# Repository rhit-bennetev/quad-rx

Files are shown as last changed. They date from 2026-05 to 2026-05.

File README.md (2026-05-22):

# quad-rx
Repository for the QuadRX gaming controller, created by Rose-Hulman 2026 ECE Capstone Team 11.

# FIRMWARE SETUP
A guide on how to use the controller from the perspective of the user is included in the final report. This guide is for power users, or manufacturers. 
We do not have access to the steps used to create the controller housing, nor integrate the basic parts such as the joystick, keycap buttons, or other ports. 
Since all of this was done by QuadRX, this guide will focus on our contribution to the project.

To compile and flash our firmware, version 2.3.7 of the Arduino IDE is required. In the future, new versions may work, but at the time of writing 
versions 2.3.8 and newer do not compile. 

Once the IDE is installed, next install the LittleFS Filesystem Uploader. This tutorial is the one we followed, and explains the process well.
https://randomnerdtutorials.com/arduino-ide-2-install-esp32-littlefs/

Next, make sure you have the newest version of git installed
https://github.com/git-guides/install-git

Clone the repository somewhere on your machine.

From here, open ControllerFirmware.ino.

Follow the steps in the LittleFS tutorial previously linked to upload the files necessary to your TinyPico. 

Then, press the arrow button in the top left corner of the IDE to compile and flash the firmware to the board. 

# HARDWARE SETUP

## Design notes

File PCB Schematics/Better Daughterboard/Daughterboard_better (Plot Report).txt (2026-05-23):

Plot Report
-----------

Report Written:     19:05 Friday, May 22, 2026
Design Path:        C:\Users\metcalwh\OneDrive - Rose-Hulman Institute of Technology\Documents\ECE362\Projects\Daughterboard_better.pcb
Design Title:       
Created:            1/16/2026 3:17:17 PM
Last Saved:         5/22/2026 7:00:21 PM
Editing Time:       15541 min
Units:              mm (precision 2)

Device Settings
===============

Gerber Settings
===============

    Leading zero suppression.
    G01 assumed throughout.
    Line termination <*> <CR> <LF>.
    3.5 format absolute inches.

    Format commands defined in Gerber file.
    Aperture table defined in Gerber file.
    Hardware arcs allowed.

Drill Settings
==============

    Excellon Format 2
    Format 3.5 absolute in mm.
    Zero suppression Leading

Plots Output
============

    Plot Job: "C:\Users\metcalwh\OneDrive - Rose-Hulman Institute of Technology\Documents\ECE362\Projects\Daughterboard_better.mop"

Gerber Output
=============

C:\Users\metcalwh\OneDrive - Rose-Hulman Institute of Technology\Documents\ECE362\Projects\Daughterboard_better - Top Gerber.gbr

    Layers:
    --------------
    Top Copper

    D-Code Shape  (thou)
    -----------------------------
    D10    Round 50.00
    D11    Round 48.00
    D12    Round 15.00
    D13    Round 25.00
    D14    Round 60.00
    D15    Square 60.00
    D16    Octagon 60.00
    D17    Oval 60.00 X 120.00

Gerber Output
=============

C:\Users\metcalwh\OneDrive - Rose-Hulman Institute of Technology\Documents\ECE362\Projects\Daughterboard_better - Bottom Gerber.gbr

    Layers:
    -----------------
    Bottom Copper

    D-Code Shape  (thou)
    -----------------------------
    D10    Round 50.00
    D11    Round 48.00
    D12    Round 15.00
    D13    Round 25.00
    D14    Round 60.00
    D15    Square 60.00
    D16    Octagon 60.00
    D17    Oval 60.00 X 120.00

NC Drill Output
===============

C:\Users\metcalwh\OneDrive - Rose-Hulman Institute of Technology\Documents\ECE362\Projects\Daughterboard_better - Drill Excellon.drl

    Output:
    ---------------------------
    Plated Round Drill Holes
    Plated Slots
    Plated Board Outlines

    Tool  Size           Count   ID
    --------------------------------------
    T001  0.02400 inches 16    A
    T002  0.03500 inches 4     B
    T003  0.04000 inches 28    F
    --------------------------------------
    Total                48
    --------------------------------------

C:\Users\metcalwh\OneDrive - Rose-Hulman Institute of Technology\Documents\ECE362\Projects\Daughterboard_better - Drill Excellon (Unplated).drl

    Output:
    -----------------------------
    Unplated Round Drill Holes
    Unplated Slots
    Unplated Board Outlines

    Tool  Size           Count   ID
    --------------------------------------
    T001  0.02500 inches 1
    --------------------------------------
    Total                1
    --------------------------------------

Gerber Output
=============

C:\Users\metcalwh\OneDrive - Rose-Hulman Institute of Technology\Documents\ECE362\Projects\Daughterboard_better - Outline.gbr

    Layers:
    ------------------
    Board Outlines

    D-Code Shape  (thou)
    -----------------------
    D18    Round 5.00

End Of Report.

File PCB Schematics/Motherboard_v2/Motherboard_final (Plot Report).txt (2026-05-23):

Plot Report
-----------

Report Written:     19:15 Friday, May 22, 2026
Design Path:        C:\Users\metcalwh\OneDrive - Rose-Hulman Institute of Technology\Documents\ECE362\Projects\Motherboard_final.pcb
Design Title:       
Created:            4/22/2026 6:35:05 PM
Last Saved:         5/22/2026 7:12:16 PM
Editing Time:       1205 min
Units:              thou (precision 3)

Device Settings
===============

Gerber Settings
===============

    Leading zero suppression.
    G01 assumed throughout.
    Line termination <*> <CR> <LF>.
    3.5 format absolute inches.

    Format commands defined in Gerber file.
    Aperture table defined in Gerber file.
    Hardware arcs allowed.

Drill Settings
==============

    Excellon Format 2
    Format 3.5 absolute in mm.
    Zero suppression Leading

Plots Output
============

Gerber Output
=============

C:\Users\metcalwh\OneDrive - Rose-Hulman Institute of Technology\Documents\ECE362\Projects\Motherboard_final - Outline.gbr

    Layers:
    ------------------
    Board Outlines

    D-Code Shape  (thou)
    -----------------------
    D10    Round 5.00

NC Drill Output
===============

C:\Users\metcalwh\OneDrive - Rose-Hulman Institute of Technology\Documents\ECE362\Projects\Motherboard_final - Excellon.drl

    Output:
    ---------------------------
    Plated Round Drill Holes
    Plated Slots
    Plated Board Outlines

    Tool  Size           Count   ID
    --------------------------------------
    T001  0.04000 inches 32    F
    --------------------------------------
    Total                32
    --------------------------------------

C:\Users\metcalwh\OneDrive - Rose-Hulman Institute of Technology\Documents\ECE362\Projects\Motherboard_final - Excellon (Unplated).drl

    Output:
    -----------------------------
    Unplated Round Drill Holes
    Unplated Slots
    Unplated Board Outlines

    Tool  Size           Count   ID
    --------------------------------------
    T001  0.02500 inches 1
    --------------------------------------
    Total                1
    --------------------------------------

Gerber Output
=============

C:\Users\metcalwh\OneDrive - Rose-Hulman Institute of Technology\Documents\ECE362\Projects\Motherboard_final - Gerber.gbr

    Layers:
    -----------------
    Bottom Copper

    D-Code Shape  (thou)
    -----------------------
    D11    Round 50.00
    D12    Round 78.74
    D13    Square 60.00
    D14    Octagon 60.00

End Of Report.

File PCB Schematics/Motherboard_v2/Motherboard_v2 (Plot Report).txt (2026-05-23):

Plot Report
-----------

Report Written:     19:49 Sunday, March 22, 2026
Design Path:        C:\Users\metcalwh\OneDrive - Rose-Hulman Institute of Technology\Documents\ECE362\Projects\Motherboard_v2.pcb
Design Title:       
Created:            1/23/2026 1:30:06 PM
Last Saved:         3/20/2026 4:17:12 PM
Editing Time:       7558 min
Units:              mm (precision 2)

Device Settings
===============

Gerber Settings
===============

    Leading zero suppression.
    G01 assumed throughout.
    Line termination <*> <CR> <LF>.
    3.5 format absolute inches.

    Format commands defined in Gerber file.
    Aperture table defined in Gerber file.
    Hardware arcs allowed.

Drill Settings
==============

    Excellon Format 2
    Format 3.5 absolute in mm.
    Zero suppression Leading

Plots Output
============

    Plot Job: "C:\Users\metcalwh\OneDrive - Rose-Hulman Institute of Technology\Documents\ECE362\Projects\Motherboard_v2.mop"

Gerber Output
=============

C:\Users\metcalwh\OneDrive - Rose-Hulman Institute of Technology\Documents\ECE362\Projects\Motherboard_v2 - Outline.gbr

    Layers:
    ------------------
    Board Outlines

    D-Code Shape  (thou)
    -----------------------
    D10    Round 5.00

Gerber Output
=============

C:\Users\metcalwh\OneDrive - Rose-Hulman Institute of Technology\Documents\ECE362\Projects\Motherboard_v2 - Top Copper.gbr

    Layers:
    --------------
    Top Copper

    D-Code Shape  (thou)
    -----------------------
    D11    Square 60.00
    D12    Octagon 60.00

Gerber Output
=============

C:\Users\metcalwh\OneDrive - Rose-Hulman Institute of Technology\Documents\ECE362\Projects\Motherboard_v2 - Bottom Copper.gbr

    Layers:
    -----------------
    Bottom Copper

    D-Code Shape  (thou)
    -----------------------
    D11    Square 60.00
    D12    Octagon 60.00
    D13    Round 50.00
    D14    Round 78.74

NC Drill Output
===============

C:\Users\metcalwh\OneDrive - Rose-Hulman Institute of Technology\Documents\ECE362\Projects\Motherboard_v2 - Drill Excellon.drl

    Output:
    ---------------------------
    Plated Round Drill Holes
    Plated Slots
    Plated Board Outlines

    Tool  Size           Count   ID
    --------------------------------------
    T001  0.04000 inches 32    F
    --------------------------------------
    Total                32
    --------------------------------------

C:\Users\metcalwh\OneDrive - Rose-Hulman Institute of Technology\Documents\ECE362\Projects\Motherboard_v2 - Drill Excellon (Unplated).drl

    Output:
    -----------------------------
    Unplated Round Drill Holes
    Unplated Slots
    Unplated Board Outlines

    Tool  Size           Count   ID
    --------------------------------------
    T001  0.02500 inches 1
    --------------------------------------
    Total                1
    --------------------------------------

End Of Report.

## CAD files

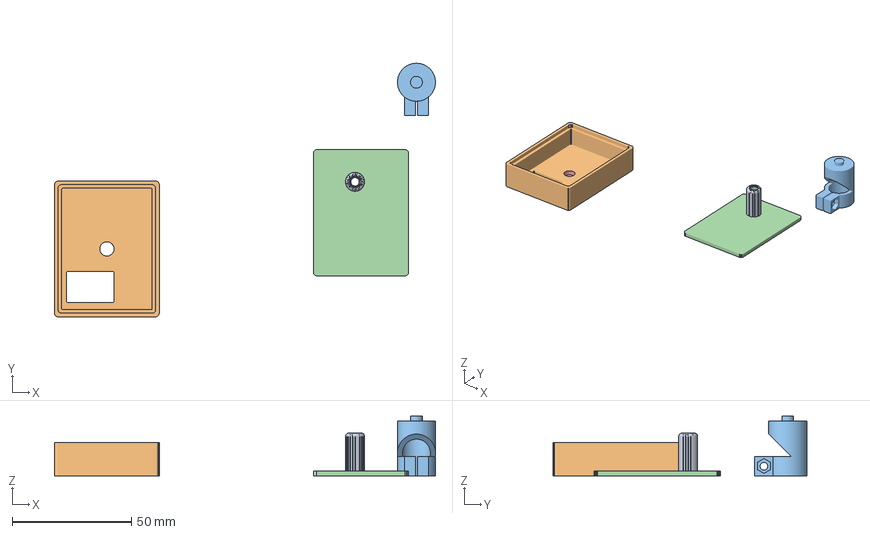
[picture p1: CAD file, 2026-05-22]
Controller Mouthpieces/1inMouthpiece-Draft1.FCStd
160.0 x 106.5 x 25.0 mm
MouthPiece001
UnderCase
JoystickConnector
MouthPiece001 (Meshed)
UnderCase (Meshed)

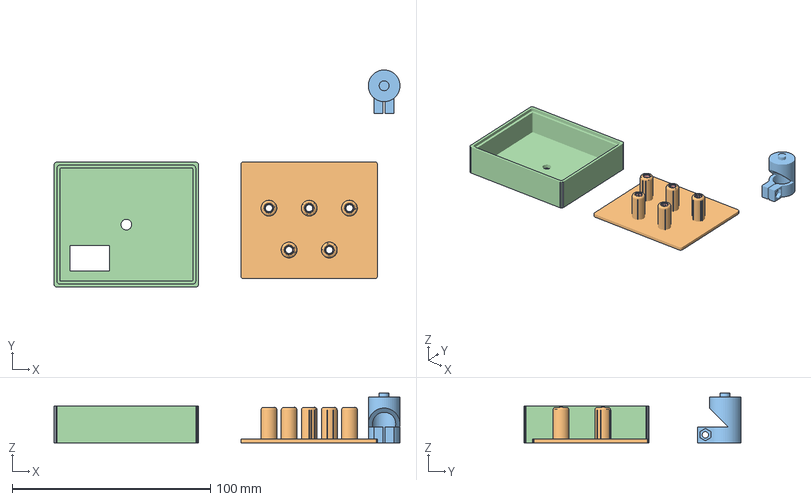
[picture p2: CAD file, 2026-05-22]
Controller Mouthpieces/5inMouthpiece-Draft11.FCStd
174.5 x 109.5 x 25.0 mm
UnderCase
MouthPiece001
JoystickConnector
UnderCase (Meshed)
MouthPiece001 (Meshed)

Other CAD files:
Controller Mouthpieces/1inMouthpiece-Draft1.stl
Controller Mouthpieces/5inMouthpiece-Draft11.stl

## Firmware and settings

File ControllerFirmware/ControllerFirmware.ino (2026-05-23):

// Captive Portal
#include <WiFi.h>
#include <AsyncTCP.h>  //https://github.com/me-no-dev/AsyncTCP using the latest dev version from @me-no-dev
#include <DNSServer.h>
#include <ESPAsyncWebServer.h>  //https://github.com/me-no-dev/ESPAsyncWebServer using the latest dev version from @me-no-dev
#include <esp_wifi.h>           //Used for mpdu_rx_disable android workaround
#include <ArduinoJson.h>        //For handling profile Jsons
#include <LittleFS.h>           //Replictes a file system on an ESP32 device.
#include "HX711.h"
#include <BleGamepad.h>

//define pressure sensors
HX711 scaleAB;
HX711 scaleXY;
HX711 scaleTrigger;

//pins for clock, joystick X and Y, and pressure sensors
const int CLK = 18;
const int joystickY = 4;
const int joystickX = 14;
const int p2 = 15;
const int p3 = 26;
const int p4 = 25;

const int key1 = 33;
const int key2 = 32;

int curState = 0;
//define threshold to register an input
//difference from base state must be > base + thres or < base - thres. some fine tuning may be required due to differences in manufactering
const int base = 700000;
const int thres = 400000;
const int baseX = 3550000;

//center of joystick in potentiometer land
const int CENTER_X_RAW = 1931;
const int CENTER_Y_RAW = 1776;

BleGamepad bleGamepad;

bool pressA = false;
bool pressB = false;
bool pressX = false;
bool pressY = false;
bool pressLT = false;
bool pressRT = false;

const int DNS_INTERVAL = 30;
// Pre reading on the fundamentals of captive portals https://textslashplain.com/2022/06/24/captive-portals/

const char *ssid = "captive";  // FYI The SSID can't have a space in it.
// const char * password = "12345678"; //Atleast 8 chars
const char *password = NULL;  // no password

#define MAX_CLIENTS 4   // ESP32 supports up to 10 but I have not tested it yet
#define WIFI_CHANNEL 6  // 2.4ghz channel 6 https://en.wikipedia.org/wiki/List_of_WLAN_channels#2.4_GHz_(802.11b/g/n/ax)

const IPAddress localIP(4, 3, 2, 1);           // the IP address the web server, Samsung requires the IP to be in public space
const IPAddress gatewayIP(4, 3, 2, 1);         // IP address of the network should be the same as the local IP for captive portals
const IPAddress subnetMask(255, 255, 255, 0);  // no need to change: https://avinetworks.com/glossary/subnet-mask/

const String localIPURL = "http://4.3.2.1";  // a string version of the local IP with http, used for redirecting clients to your webpage

String currentProfile = "default";

String profilePath(String name) {
	return "/profiles/" + name + ".json";
}

// Maps a sensor port + direction to a BLE button
struct SensorBinding {
	int buttonId;
	bool isPuff;
};

struct SensorConfig {
	SensorBinding puff;
	SensorBinding sip;
	bool hasPuff = false;
	bool hasSip = false;
	float base;
	float threshold;
};


struct SensorConfig cfgSP1, cfgSP2, cfgSP3;

int resolveButton(const char *name) {
	// Map your button name strings to BLE button constants
	if (strcmp(name, "A") == 0) return BUTTON_1;
	if (strcmp(name, "B") == 0) return BUTTON_2;
	if (strcmp(name, "X") == 0) return BUTTON_3;
	if (strcmp(name, "Y") == 0) return BUTTON_4;
	return -1;  // unrecognized
}

void parseSensorBindings(JsonObject &sp, struct SensorConfig &cfg) {  //relevant to loadActiveProfile, parses whatever config is current and stores it in the config structs
	cfg.hasPuff = false;
	cfg.hasSip = false;

	for (JsonPair kv : sp) {
		const char *buttonName = kv.key().c_str();
		const char *action = kv.value().as<const char *>();
		int btnId = resolveButton(buttonName);
		if (btnId == -1) continue;

		if (strcmp(action, "puff") == 0) {
			cfg.puff = { btnId, true };
			cfg.hasPuff = true;
		} else if (strcmp(action, "sip") == 0) {
			cfg.sip = { btnId, false };
			cfg.hasSip = true;
		}
	}
}

void loadActiveProfile() {  //i'll be honest i dont SUPER know how this works but from all the stuff ive looked at online + asking claude a bit it should be good.
	String filename = profilePath(currentProfile);
	if (!LittleFS.exists(filename)) {
		Serial.println("No profile found, using defaults");
		// default configuration if user hasnt made one
		cfgSP1 = { { BUTTON_4, true }, { BUTTON_3, false }, true, true, (float)baseX, (float)thres };
		cfgSP2 = { { BUTTON_1, true }, { BUTTON_2, false }, true, true, (float)base, (float)thres };
		return;
	}

	File file = LittleFS.open(filename, "r");
	DynamicJsonDocument doc(2048);
	deserializeJson(doc, file);
	file.close();

	JsonObject bindings = doc["bindings"];

	if (bindings.containsKey("SP1")) {
		JsonObject sp1 = bindings["SP1"];
		cfgSP1.base = baseX;
		cfgSP1.threshold = thres;
		parseSensorBindings(sp1, cfgSP1);
	}
	if (bindings.containsKey("SP2")) {
		JsonObject sp2 = bindings["SP2"];
		cfgSP2.base = base;
		cfgSP2.threshold = thres;
		parseSensorBindings(sp2, cfgSP2);
	}
	if (bindings.containsKey("SP3")) {
		JsonObject sp3 = bindings["SP3"];
		cfgSP3.base = base;  // adjust if SP3 has a different base
		cfgSP3.threshold = thres;
		parseSensorBindings(sp3, cfgSP3);
	}

	Serial.println("Loaded profile: " + currentProfile);
}

void handleSensor(HX711 &scale, struct SensorConfig &cfg, bool &pressHigh, bool &pressLow) {  //put this in its own function because it was ugly to have it all in loop()
	if (!scale.is_ready()) return;
	float val = scale.read();

	// Puff
	if (cfg.hasPuff) {
		if (val > (cfg.base + cfg.threshold) && !pressHigh) {
			bleGamepad.press(cfg.puff.buttonId);
			pressHigh = true;
		} else if (val <= (cfg.base + cfg.threshold) && pressHigh) {
			bleGamepad.release(cfg.puff.buttonId);
			pressHigh = false;
		}
	}

	// Sip
	if (cfg.hasSip) {
		if (val < (cfg.base - cfg.threshold) && !pressLow) {
			bleGamepad.press(cfg.sip.buttonId);
			pressLow = true;
		} else if (val >= (cfg.base - cfg.threshold) && pressLow) {
			bleGamepad.release(cfg.sip.buttonId);
			pressLow = false;
		}
	}
}


DNSServer dnsServer;
AsyncWebServer server(80);

void setUpDNSServer(DNSServer &dnsServer, const IPAddress &localIP) {
	// Define the DNS interval in milliseconds between processing DNS request

	// Set the TTL for DNS response and start the DNS server
	dnsServer.setTTL(3600);
	dnsServer.start(53, "*", localIP);
}

void startSoftAccessPoint(const char *ssid, const char *password, const IPAddress &localIP, const IPAddress &gatewayIP) {
// Define the maximum number of clients that can connect to the server
#define MAX_CLIENTS 4
// Define the WiFi channel to be used (channel 6 in this case)
#define WIFI_CHANNEL 6

	// Set the WiFi mode to access point and station
	WiFi.mode(WIFI_MODE_AP);

	// Define the subnet mask for the WiFi network
	const IPAddress subnetMask(255, 255, 255, 0);

	// Configure the soft access point with a specific IP and subnet mask
	WiFi.softAPConfig(localIP, gatewayIP, subnetMask);

	// Start the soft access point with the given ssid, password, channel, max number of clients
	WiFi.softAP(ssid, password, WIFI_CHANNEL, 0, MAX_CLIENTS);

	// Disable AMPDU RX on the ESP32 WiFi to fix a bug on Android
	esp_wifi_stop();
	esp_wifi_deinit();
	wifi_init_config_t my_config = WIFI_INIT_CONFIG_DEFAULT();
	my_config.ampdu_rx_enable = false;
	esp_wifi_init(&my_config);
	esp_wifi_start();
	vTaskDelay(100 / portTICK_PERIOD_MS);  // Add a small delay
}

void setUpWebserver(AsyncWebServer &server, const IPAddress &localIP) {
	//======================== Webserver ========================
	// WARNING IOS (and maybe macos) WILL NOT POP UP IF IT CONTAINS THE WORD "Success" https://www.esp8266.com/viewtopic.php?f=34&t=4398
	// SAFARI (IOS) IS STUPID, G-ZIPPED FILES CAN'T END IN .GZ https://github.com/homieiot/homie-esp8266/issues/476 this is fixed by the webserver serve static function.
	// SAFARI (IOS) there is a 128KB limit to the size of the HTML. The HTML can reference external resources/images that bring the total over 128KB
	// SAFARI (IOS) popup browser has some severe limitations (javascript disabled, cookies disabled)

	// Required
	server.on("/connecttest.txt", [](AsyncWebServerRequest *request) {
		request->redirect("http://logout.net");
	});  // windows 11 captive portal workaround
	server.on("/wpad.dat", [](AsyncWebServerRequest *request) {
		request->send(404);
	});  // Honestly don't understand what this is but a 404 stops win 10 keep calling this repeatedly and panicking the esp32 :)

	// Background responses: Probably not all are Required, but some are. Others might speed things up?
	// A Tier (commonly used by modern systems)
	server.on("/generate_204", [](AsyncWebServerRequest *request) {
		request->redirect(localIPURL);
	});  // android captive portal redirect
	server.on("/redirect", [](AsyncWebServerRequest *request) {
		request->redirect(localIPURL);
	});  // microsoft redirect
	server.on("/hotspot-detect.html", [](AsyncWebServerRequest *request) {
		request->redirect(localIPURL);
	});  // apple call home
	server.on("/canonical.html", [](AsyncWebServerRequest *request) {
		request->redirect(localIPURL);
	});  // firefox captive portal call home
	server.on("/success.txt", [](AsyncWebServerRequest *request) {
		request->send(200);
	});  // firefox captive portal call home
	server.on("/ncsi.txt", [](AsyncWebServerRequest *request) {
		request->redirect(localIPURL);
	});  // windows call home

	// B Tier (uncommon)
	//  server.on("/chrome-variations/seed",[](AsyncWebServerRequest *request){request->send(200);}); //chrome captive portal call home
	//  server.on("/service/update2/json",[](AsyncWebServerRequest *request){request->send(200);}); //firefox?
	//  server.on("/chat",[](AsyncWebServerRequest *request){request->send(404);}); //No stop asking Whatsapp, there is no internet connection
	//  server.on("/startpage",[](AsyncWebServerRequest *request){request->redirect(localIPURL);});

	// return 404 to webpage icon
	server.on("/favicon.ico", [](AsyncWebServerRequest *request) {
		request->send(404);
	});  // webpage icon

	// the catch all
	server.onNotFound([](AsyncWebServerRequest *request) {
		request->redirect(localIPURL);
		Serial.print("onnotfound ");
		Serial.print(request->host());  // This gives some insight into whatever was being requested on the serial monitor
		Serial.print(" ");
		Serial.print(request->url());
		Serial.print(" sent redirect to " + localIPURL + "\n");
	});
}

void listDir(fs::FS &fs, const char *dirname, uint8_t levels) {
	Serial.printf("Listing directory: %s\n", dirname);

	File root = fs.open(dirname);
	if (!root) {
		Serial.println("Failed to open directory");
		return;
	}
	if (!root.isDirectory()) {
		Serial.println("Not a directory");
		return;
	}

	File file = root.openNextFile();
	while (file) {
		if (file.isDirectory()) {
			Serial.print("  DIR : ");
			Serial.println(file.name());
			if (levels) {
				listDir(fs, file.path(), levels - 1);
			}
		} else {
			Serial.print("  FILE: ");
			Serial.print(file.name());
			Serial.print("  SIZE: ");
			Serial.println(file.size());
		}
		file = root.openNextFile();
	}

	Serial.print("Current Profile: ");
	Serial.println(currentProfile);
}

BleGamepadConfiguration config;

void setup() {
	// Set the transmit buffer size for the Serial object and start it with a baud rate of 115200.
	Serial.setTxBufferSize(1024);
	Serial.begin(115200);
	// Wait for the Serial object to become available.
	while (!Serial)
		;

	// Print a welcome message to the Serial port.
	Serial.printf("%s-%d\n\r", ESP.getChipModel(), ESP.getChipRevision());

	startSoftAccessPoint(ssid, password, localIP, gatewayIP);

	setUpDNSServer(dnsServer, localIP);

	if (!LittleFS.begin(true)) {
		Serial.println("LittleFS Mount Failed!");
		return;
	}

	if (!LittleFS.exists("/profiles")) {
		LittleFS.mkdir("/profiles");
	}
	delay(100);
	Serial.println("Files on TinyPICO:");
	Serial.println("------------------------");
	listDir(LittleFS, "/", 3);  // List all files, 3 levels deep
	Serial.println("------------------------\n");

	setupEndpoints();

	setUpWebserver(server, localIP);
	server.begin();

	config.setControllerType(CONTROLLER_TYPE_GAMEPAD);
	//config.setVid(0x045e);
	//config.setPid(0x028e);

	bleGamepad.begin(&config);

	//Serial.println("Initializing HX711 sensors...");
	scaleAB.begin(p2, CLK);
	delay(100);
	scaleXY.begin(p3, CLK);
	delay(100);
	scaleTrigger.begin(p4, CLK);
	delay(100);

	pinMode(key1, INPUT_PULLUP);
	pinMode(key2, INPUT_PULLUP);

	loadActiveProfile();

	Serial.print("\n");
	Serial.print("Startup Time:");
	Serial.println(millis());
	Serial.print("\n");
}

void setupEndpoints() {
	//Serve Website
	server.serveStatic("/", LittleFS, "/").setDefaultFile("Main.html");

	//Save Profile
	server.on(
	  "/saveProfile", HTTP_POST, [](AsyncWebServerRequest *request) {}, NULL, [](AsyncWebServerRequest *request, uint8_t *data, size_t len, size_t index, size_t total) {
		  DynamicJsonDocument doc(2048);
		  if (deserializeJson(doc, data)) {
			  request->send(400, "application/json", "{\"error\":\"Bad JSON\"}");
			  return;
		  }

		  String profileName = doc["profile"];
		  JsonObject bindings = doc["bindings"];

		  if (profileName == "") {
			  request->send(400, "application/json", "{\"error\":\"Missing profile name\"}");
			  return;
		  }

		  currentProfile = profileName;
		  String filename = profilePath(profileName);

		  File file = LittleFS.open(filename, "w");
		  if (!file) {
			  request->send(500, "application/json", "{\"error\":\"Write failed\"}");
			  return;
		  }

		  serializeJson(bindings, file);
		  file.close();

		  Serial.println("Saved: " + filename);

		  loadActiveProfile();

		  request->send(200, "application/json", "{\"status\":\"Profile saved\"}");
	  });

	//Load Profile by Name
	server.on("/loadConfig", HTTP_GET, [](AsyncWebServerRequest *request) {
		if (!request->hasParam("profile")) {
			request->send(400, "application/json", "{\"error\":\"Missing profile parameter\"}");
			return;
		}

		String profileName = request->getParam("profile")->value();
		String filename = profilePath(profileName);

		if (!LittleFS.exists(filename)) {
			request->send(404, "application/json", "{\"error\":\"Profile not found\"}");
			return;
		}

		File file = LittleFS.open(filename, "r");
		String json = file.readString();
		file.close();

		currentProfile = profileName;

		loadActiveProfile();

		request->send(200, "application/json", json);
	});

	// List All Profiles
	server.on("/listProfiles", HTTP_GET, [](AsyncWebServerRequest *request) {
		File root = LittleFS.open("/profiles");
		if (!root || !root.isDirectory()) {
			request->send(500, "application/json", "{\"error\":\"Profiles folder missing\"}");
			return;
		}

		DynamicJsonDocument doc(2048);
		JsonArray arr = doc.to<JsonArray>();

		File file = root.openNextFile();
		while (file) {
			String name = file.name();  // "/profiles/test.json"
			name.replace("/profiles/", "");
			name.replace(".json", "");
			arr.add(name);

			file = root.openNextFile();
		}

		String output;
		serializeJson(arr, output);

		request->send(200, "application/json", output);
	});

	// Delete Profile
	server.on("/deleteProfile", HTTP_DELETE, [](AsyncWebServerRequest *request) {
		if (!request->hasParam("profile")) {
			request->send(400, "application/json", "{\"error\":\"Missing profile\"}");
			return;
		}

		String profileName = request->getParam("profile")->value();
		String filename = profilePath(profileName);

		if (!LittleFS.exists(filename)) {
			request->send(404, "application/json", "{\"error\":\"Profile not found\"}");
			return;
		}

		LittleFS.remove(filename);

		request->send(200, "application/json", "{\"status\":\"Profile deleted\"}");
	});
}

int lastState = -1;
void loop() {
	//listDir(LittleFS, "/", 3);

	int switchKey = digitalRead(key1);
	if (switchKey == LOW) {
		curState = !curState;
		delay(500);  // debounce
	}
	int switchKey2 = digitalRead(key2);
	if (switchKey2 == LOW) {
		listDir(LittleFS, "/", 3);
		delay(100);
	}
	if (curState != lastState) {
		lastState = curState;
		switch (curState) {
			case 0:
				esp_wifi_stop();
				Serial.println("WIFI OFF");
				break;
			case 1:
				esp_wifi_start();
				Serial.println("WIFI ON");
				break;
		}
	}

	if (curState == 1) {
		dnsServer.processNextRequest();
		delay(DNS_INTERVAL);
	}

	if (bleGamepad.isConnected()) {
		//read from joystick
		uint16_t rawx = analogRead(joystickX);
		uint16_t rawy = analogRead(joystickY);

		rawx = constrain(rawx, 750, 3500);
		rawy = constrain(rawy, 750, 3500);

		// X is inverted (left=4095, right=0), so flip it
		uint16_t mappedX = map(rawx, 3500, 750, 0, 32767);  //six seven
		// Y: up=0, down=4095 - joy.cpl wants up=0 so no flip needed
		uint16_t mappedY = map(rawy, 750, 3500, 0, 32767);


		bleGamepad.setX(mappedX);
		bleGamepad.setY(mappedY);

		handleSensor(scaleAB, cfgSP2, pressB, pressA);
		handleSensor(scaleXY, cfgSP1, pressX, pressY);
		handleSensor(scaleTrigger, cfgSP3, pressLT, pressRT);
	}
}

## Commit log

2026-01-22 Controller Backgrounds and Flexing
    Controller backgrounds have place holder images and everything has been flexed to fit on Iphone and scale properly. Next steps is getting buttons overlayed and switching properly.
2026-02-05 Front-end save and load
    Save button now names and saves configurations using a const list that is sent to the server as a JSON using a place holder post method. Likewise there is a place holder method for loading configs fr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
2026-02-11 LittleFS and Endpoints Implementation v1
    Attempted to implement littleFS in quadRxWeb_copy, have not tested it because I do not have the tinyPico, and the internet says I need something called ESP32 LittleFS Upload, Also needs to upload the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
2026-02-21 Selection box and load/delete
    I added a selection box and load/delete functionality (in theory). load configs menu button has been replaced with a manage configs option that pulls up a drop down that allows users to select a profile then either delete or load it. added the bones of some favoriting functionality, need to test load/delete and add an "are you sure about that" for the delete button.
2026-02-22 Save/Load changes
    made some changes to save/load to try and get the selection list to populate. collapsed delete functions into 1, but left the old one just in case its needed for like console calls n'stuff
2026-02-22 fixed new controller popup
    new controller background switching works again
2026-02-22 Changed directories
    now we don't have to keep editing the files we flash to the pico
2026-03-16 New config data struc, plus attempt at stage 1 glow
    I reorganized the JSON format for using the sip/puff sensors to map and configure inputs, not sure if it will be final choice or not. Current design does not allow for multiple sip/puffs to be config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
2026-03-22 PCB Schematics
2026-03-31 Multicolored Glow
    Each sensor has it's own color and the buttons glow when configured in that color
2026-05-22 Committing all mouthpiece designs
    [1inMouthpiece-Draft1.FCStd, 1inMouthpiece-Draft1.stl, 5inMouthpiece-Draft11.FCStd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]
2026-05-23 PCB Schematics and slight firmware revision
    [Daughterboard_better - Bottom Gerber.gbr, Daughterboard_better - Drill Excellon (Unplated).drl, Daughterboard_better - Drill Excellon.drl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]
